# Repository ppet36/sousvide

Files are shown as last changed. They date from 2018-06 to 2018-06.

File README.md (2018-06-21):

# DIY Sous Vide cooker

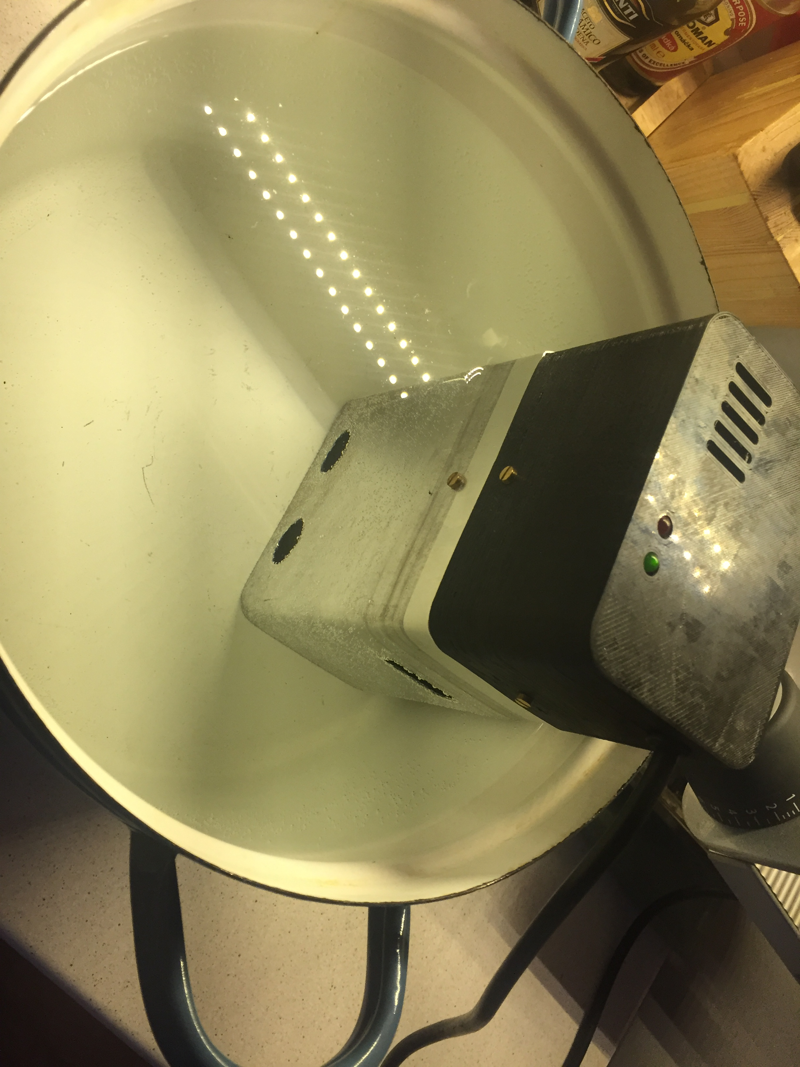
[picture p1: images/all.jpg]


This repository contains resources for my DIY WiFi Sous Vide cooker. Repo contains
responsive Angular/Bootstrap application for setting cooking parameters and manage
cooker, Eagle PCB design w/ schematic and 3D model of enclosure.

Cooker are based on ESP12E (or ESP07) module, submersible heater PROFESSOR PO500 and
EHEIM Compact 300 aquarium pump.
For measuring temperature watertight DS18B20 sensor is used. Analog
ESP PIN is used for detecting water level and protecting "dry" run of cooker.
Some parts are printed on 3D printer, bottom part of cooker is bended aluminium
sheet.

Memory of ESP12E is divided into two parts; 1M for firmware and 3M for SPIFFS.
Application (arduino/data/*) is uploaded to ESP's SPIFFS and is served via
internal HTTP server. Firmware creates AP SousVideCooker with listening HTTP server
at:

```
http://192.168.4.1/
```
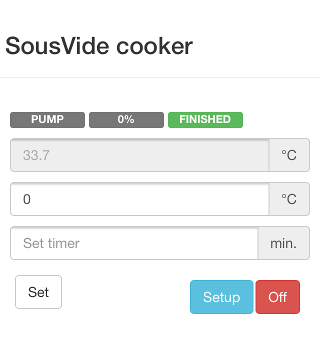
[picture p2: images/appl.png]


AP password is defaulted to 123456 and can be set in fw source file.

Via application can be also set PID parameters for heater. Firmware uses AutoPID
library from https://github.com/r-downing/AutoPID.
Also other Arduino libraries is used https://github.com/milesburton/Arduino-Temperature-Control-Library,
https://github.com/bblanchon/ArduinoJson ...

Heater as well as pump is driven via triacs. Duo MOC3041/BT136 is used for heater
and plain MOC3041 for pump (which is only 5W). For 500W heater is not needed
additional BT136 cooling but small TO220 heatsink is suitable.

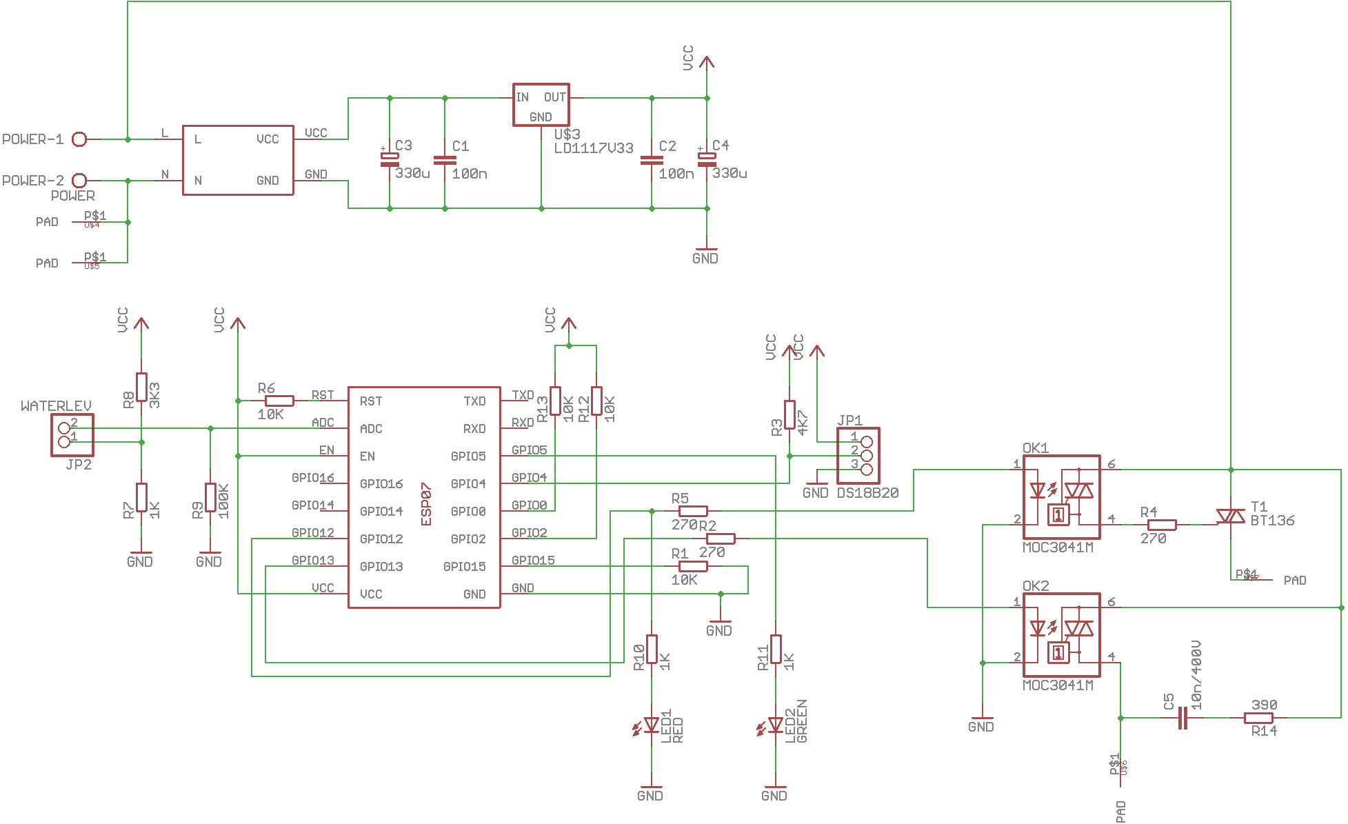
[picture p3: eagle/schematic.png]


Module is powered via 5V/1A PSU. Many of theses is on ebay; for example:
https://www.ebay.com/sch/i.html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
You can use also 3.3V PSU instead of 5V; so linear regulator is not needed.

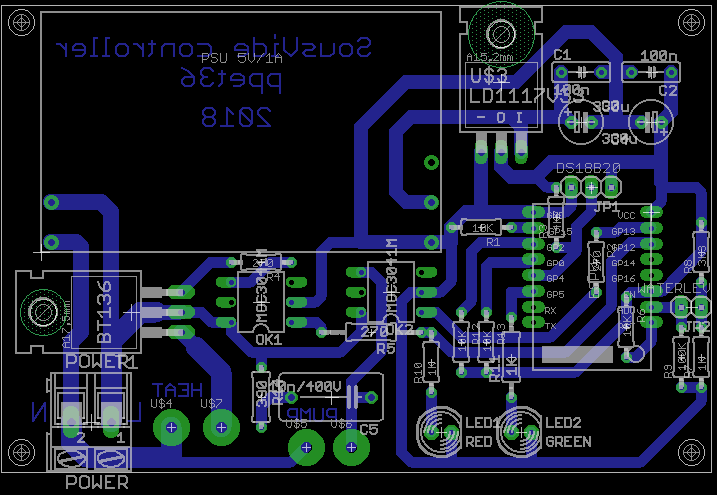
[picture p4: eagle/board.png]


PCB is designed to fit on top of mounting cube. All connections (except of power supply cord)
is connected from bottom side of PCB.

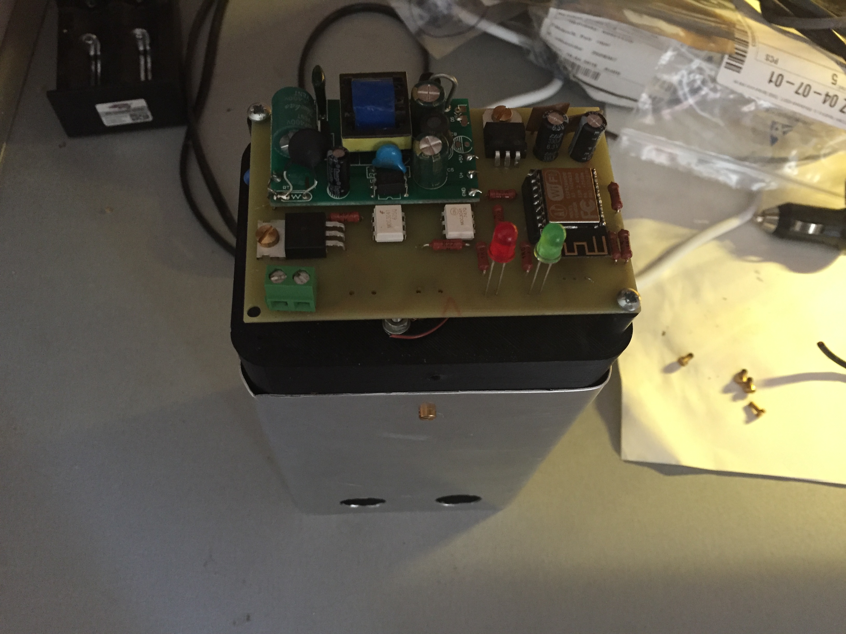
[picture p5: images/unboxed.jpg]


(PCB in image is working prototype and not looking exactly same as in eagle/* resources;
I modified schematic and PCB layout later taking experiences into account)

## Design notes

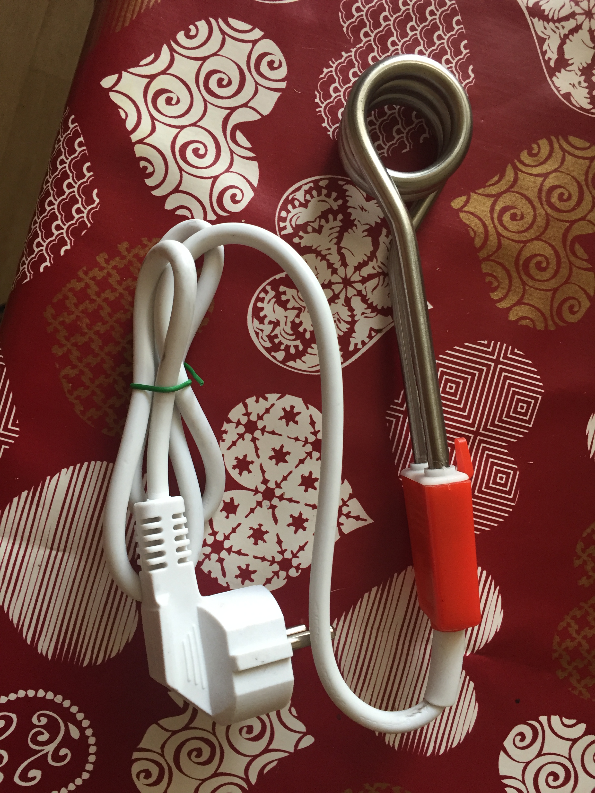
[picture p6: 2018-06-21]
images/heater.jpg

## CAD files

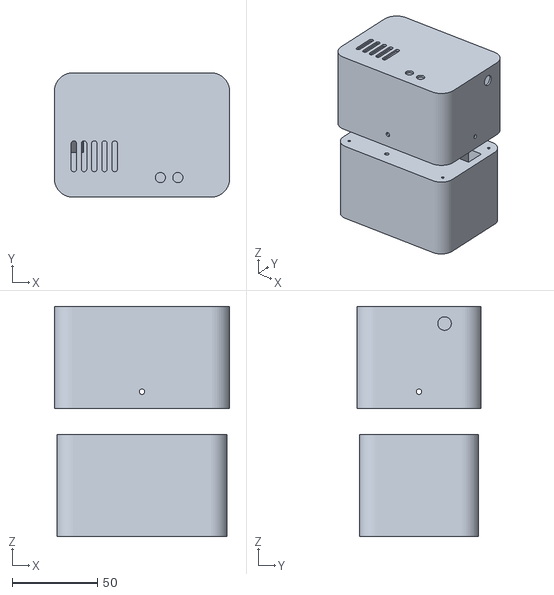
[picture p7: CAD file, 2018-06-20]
openscad/svbox.stl
103.0 x 73.0 x 135.0

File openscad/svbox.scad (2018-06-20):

$fn=30;

module roundedRect(size, radius) {
  x = size[0];
  y = size[1];
  z = size[2];

  translate([0,0,-z/2]) linear_extrude (height=z) hull($fn=50) {
    translate([(-x/2)+(radius/2), (-y/2)+(radius/2), 0])
    circle(r=radius);

    translate([(x/2)-(radius/2), (-y/2)+(radius/2), 0])
    circle(r=radius);

    translate([(-x/2)+(radius/2), (y/2)-(radius/2), 0])
    circle(r=radius);

    translate([(x/2)-(radius/2), (y/2)-(radius/2), 0])
    circle(r=radius);
  }
}

module eheimPump() {
  union() {
    cube ([42, 34, 28], center=true);
    translate([-28,0,-20]) rotate([0,90,0]) cylinder (d=12, h=15, center=true, $fn=50);
    translate([15,9.5,28]) cube ([12, 15, 30], center=true);
    translate([0,0,-25]) cube ([42, 34, 22], center=true);
    translate([28,0,-31]) cube ([15,34,10], center=true);
    translate([-20,0,-33]) rotate([90,0,0]) cylinder (d=50, h=34, center=true, $fn=100);
  }
}

module heater() {
  union() {
   hull() {
     translate([0,0,20]) cube ([10, 20, 1], center=true);
     translate([0,0,-20]) cube ([10, 24.5, 1], center=true);
   }
   translate([0,0,30]) cylinder (d=7, h=20, center=true, $fn=30);
   translate([0,0,-45.5]) cube ([14,29,50], center=true);
  }
}

module toCut() {
  translate([-30,0,0]) {
    translate([-5,0,13]) rotate([0,-15,0]) heater();
    translate([53,0,-5]) eheimPump();
    //translate([55,25,0]) cube([5,2,200], center=true);
    //translate([55,-25,0]) cube([5,2,200], center=true);
    translate([20,12,-25]) ds18b20();
    translate([20,-25,-25]) cylinder (d=3.2, h=200, center=true, $fn=30);
    translate([20,25,-25]) cylinder (d=3.2, h=200, center=true, $fn=30);
  }
}

module holderBox() {
  difference() {
    roundedRect ([90, 60, 60], 10); 
    toCut();
  
    translate([-43,-27,21]) cylinder (d=2, h=20, center=true);
    translate([-43,27,21]) cylinder (d=2, h=20, center=true);
    translate([43,-27,21]) cylinder (d=2, h=20, center=true);
    translate([43,27,21]) cylinder (d=2, h=20, center=true);
  }
}

module ds18b20() {
  union() {
    cylinder (d=6, h=35, center=true, $fn=50);
    translate([0,0,25]) cylinder (d=6.5, h=15, center=true, $fn=50);
    translate([0,0,57]) cylinder (d=6.5, h=50, center=true, $fn=50);
  }
}

module vetrani() {
  hull() {
    cylinder (d=3.2, h=100, center=true);
    translate([0,15,0]) cylinder (d=3.2, h=100, center=true);
  }
}

module okraj() {
  difference() {
    union() {
      translate([0,0,29.25]) roundedRect ([92, 62, 1.5], 10);
      difference() {
        roundedRect([92, 62, 60], 11);
        roundedRect([90.3, 60.3, 60.1], 10);
      }
    }
    
    translate([-45+55.8,-30+5,0]) cylinder (d=6, h=200, center=true);
    translate([-45+66.04,-30+5,0]) cylinder (d=6, h=200, center=true);
    translate([0,0,-20]) rotate([90,0,0]) cylinder (d=3.2, h=200, center=true);
    translate([0,0,-20]) rotate([90,0,90]) cylinder (d=3.2, h=200, center=true);
    translate([50,15,20]) rotate([90,0,90]) cylinder (d=8, h=50, center=true);
    
    translate([-40,-20,0]) vetrani();
    translate([-40+6,-20,0]) vetrani();
    translate([-40+12,-20,0]) vetrani();
    translate([-40+18,-20,0]) vetrani();
    translate([-40+24,-20,0]) vetrani();
  }
}

module vyrez() {
   rotate([0,-90,0]) 
   hull() {
     cube ([30,30,5], center=true);
     translate([20,0,0]) cylinder (d=30, h=5, center=true);
   }  
}

holderBox();
translate([0,0,75]) okraj();

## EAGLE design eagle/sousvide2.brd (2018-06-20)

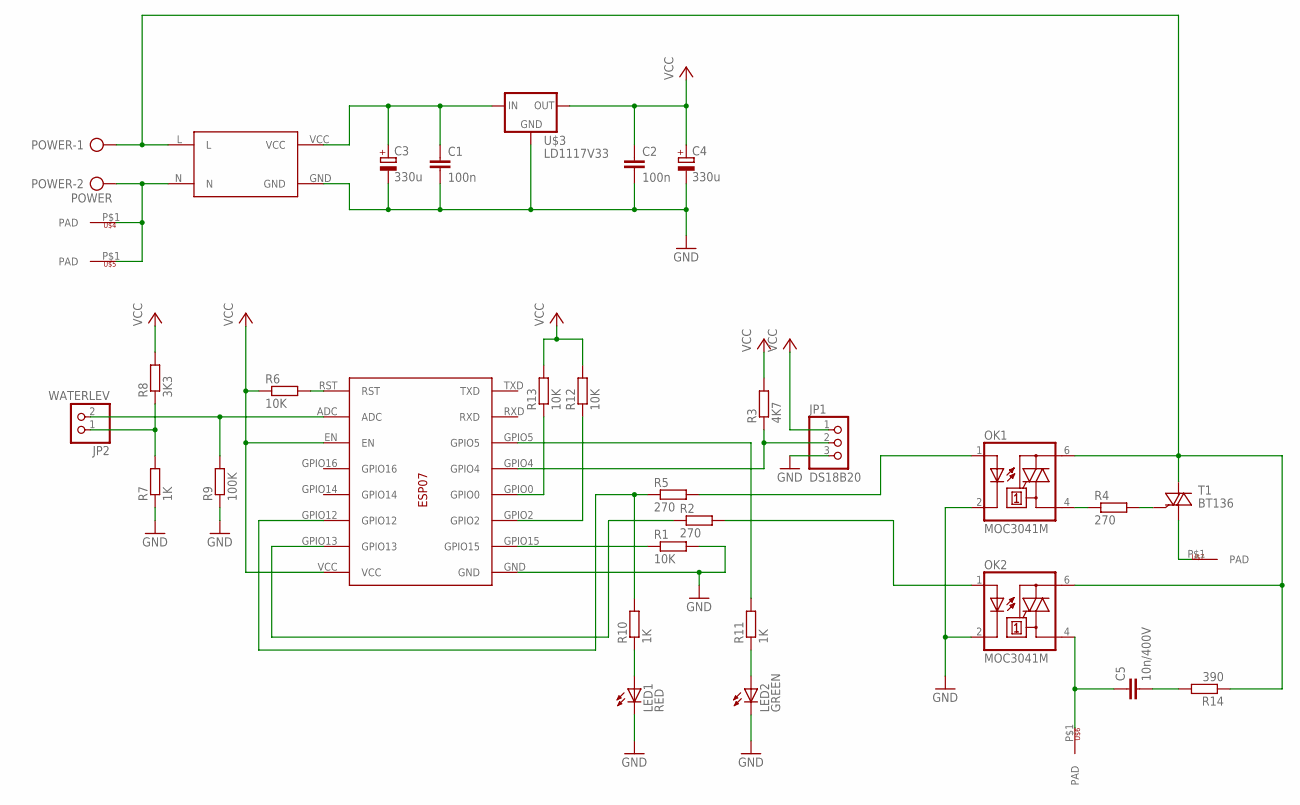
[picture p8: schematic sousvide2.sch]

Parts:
C1, C2: 100n; C050-025X075
C3, C4: 330u; E2,5-6
C5: 10n/400V; C102-064X133
JP1: DS18B20; 1X03
JP2: WATERLEV; 1X02
LED1: RED; LED5MM
LED2: GREEN; LED5MM
OK1, OK2: MOC3041M; DIL06
POWER: POWER; AK300/2
R1, R6, R12, R13: 10K; 0204/7
R2, R4: 270; 0204/7
R3: 4K7; 0204/7
R5: 270; 0207/12
R7, R10: 1K; 0204/7
R8: 3K3; 0204/7
R9: 100K; 0204/7
R11: 1K; 0207/10
R14: 390; 0207/7
T1: BT136; TO220AB
U$1: ESP12F; ESP07
U$2: PSU5V1A; PSU5V
U$3: LD1117V33
U$4, U$5, U$6, U$7: PAD

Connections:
GND: C1.2, C2.2, C3.-, C4.-, JP1.3, LED1.K (C), LED2.K (C), OK1.2 (C), OK2.2 (C), R1.2, R7.1, R9.1, U$1.GND, U$2.GND, U$3.GND
unnamed: R1.1, U$1.GPIO15
unnamed: R2.1, U$1.GPIO13
unnamed: OK1.4 (A1), R4.1
unnamed: R4.2, T1.3 (G)
unnamed: C1.1, C3.+, U$2.VCC, U$3.IN
unnamed: POWER.2, U$2.N, U$4.P$1, U$5.P$1
unnamed: OK1.6 (A2), OK2.6 (A2), POWER.1, R14.1, T1.2 (A2), U$2.L
unnamed: LED1.A, R10.1
unnamed: T1.1 (A1), U$7.P$1
unnamed: R13.1, U$1.GPIO0
unnamed: R5.1, R10.2, U$1.GPIO12
unnamed: OK1.1 (A), R5.2
unnamed: LED2.A, R11.1
unnamed: OK2.1 (A), R2.2
unnamed: R11.2, U$1.GPIO5
unnamed: C5.1, OK2.4 (A1), U$6.P$1
unnamed: JP1.2, R3.1, U$1.GPIO4
unnamed: R12.1, U$1.GPIO2
unnamed: R6.2, U$1.RST
unnamed: JP2.2, R9.2, U$1.ADC
unnamed: JP2.1, R7.2, R8.1
unnamed: C5.2, R14.2
VCC: C2.1, C4.+, JP1.1, R3.2, R6.1, R8.2, R12.2, R13.2, U$1.EN, U$1.VCC, U$3.OUT

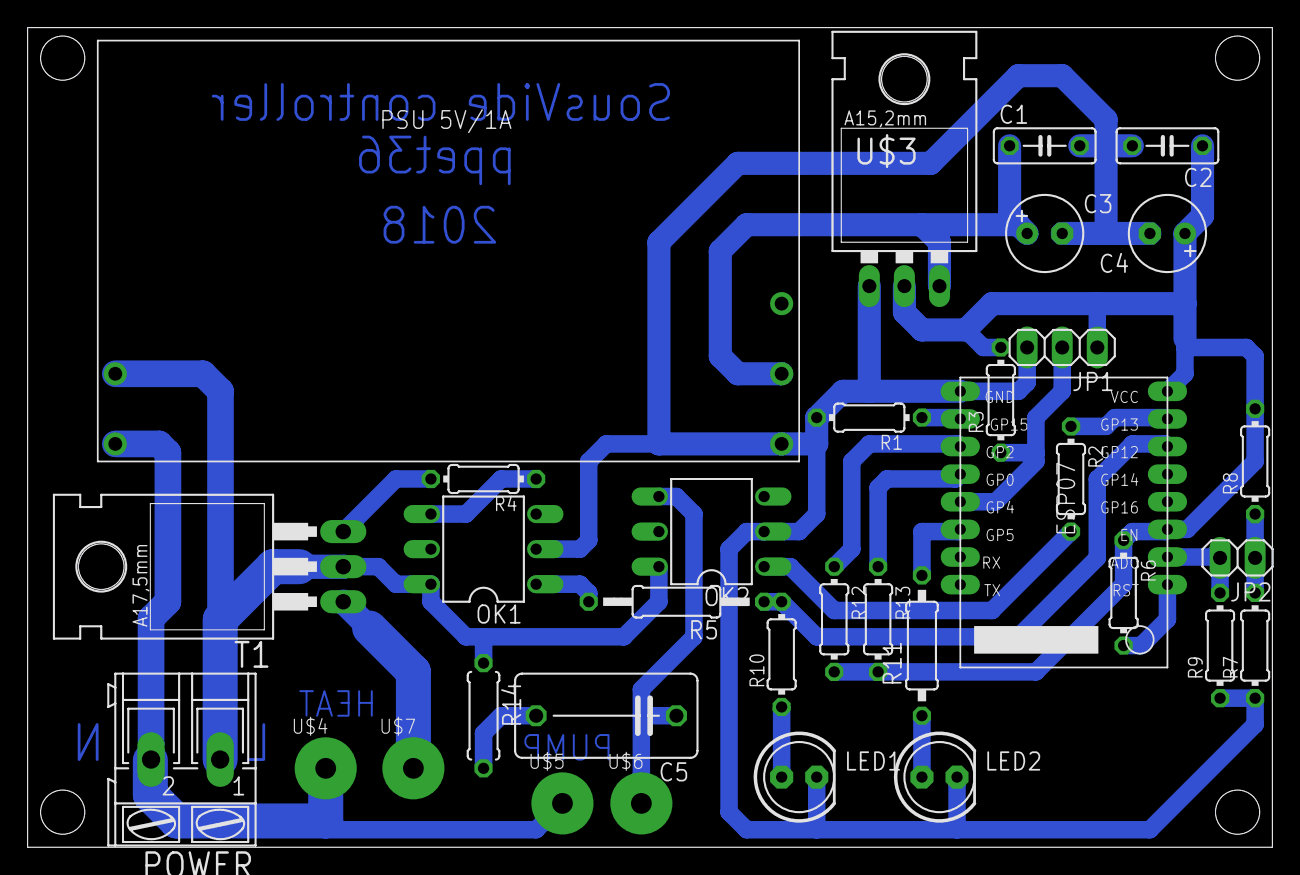
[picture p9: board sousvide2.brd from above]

Board: 2 copper layers, 90.2 x 59.4 mm, 34 parts (0 on the bottom side), 24 nets.

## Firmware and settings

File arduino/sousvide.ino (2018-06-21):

/**
 * SousVide controller for ESP12F or ESP07.
 *
 * Pins asignment:
 *
 * ADC     - water level sensor.
 * GPIO12  - triac switch for heater.
 * GPIO13  - triac switch for pump.
 * GPIO4   - OneWire DS18B20
 * GPIO5   - green status led.
 *
 * Code uses ArduinoJson, SPIFFS and OTA library.
 *
 * @author ppet36
*/
#include <AutoPID.h>
#include <DallasTemperature.h>
#include <OneWire.h>
#include <EEPROM.h>
#include <ESP8266WiFi.h>
#include <ESP8266HTTPClient.h>
#include <WiFiClient.h>
#include <ESP8266WebServer.h>
#include <FS.h>
#include <ArduinoJson.h>
#include <ArduinoOTA.h>

// WIFI
#define WIFI_AP_SSID "SousVideCooker"
#define WIFI_AP_PWD "123456"
#define WEB_SERVER_PORT 80

#define PIN_WATER_LEVEL A0
#define PIN_HEATER      12
#define PIN_PUMP        13
#define PIN_ONEWIRE     4
#define PIN_STATUS      5

// PWM heater window size
#define PWM_HEATER_WINDOW_SIZE    5000

// PID settings
#define DEFAULT_KP 0.12
#define DEFAULT_KI 0.0003
#define DEFAULT_KD 0
#define DEFAULT_PID_BANG 1.0

// DS18B20 temp is readed once 800ms
#define TEMP_READ_DELAY 800

// ADC value (greater values means enough water)
#define WATER_LEVEL_LIMIT  350

// States
#define ST_OFF      0x00
#define ST_NO_WATER 0x01
#define ST_RUNNING  0x02
#define ST_FINISHED 0x03

// Current eeprom magic for detecting unconfigured module
#define MAGIC 0xAA

// EEPROM structure for configuration
struct SvConfiguration {
  int magic;
  double kp;
  double ki;
  double kd;
  double bang;
};

// DS18B20
OneWire oneWire (PIN_ONEWIRE);
DallasTemperature temperatureSensors (&oneWire);

// PID values
double curTemperature, reqTemperature;
bool heaterVal;

// PID
AutoPIDRelay myPID (&curTemperature, &reqTemperature, &heaterVal, PWM_HEATER_WINDOW_SIZE, DEFAULT_KP, DEFAULT_KI, DEFAULT_KD);

// Configuration server
ESP8266WebServer server (WEB_SERVER_PORT);

// Water level indication
int waterLevelAdc;
bool waterLevel;

// Timer; requested time (mins)
unsigned long timerStopTime = 0UL;
int timerMins = 0;
bool timerTargetTempReached = true;

// Configuration
SvConfiguration config;

// Current state
int state;

// Last heater on time
unsigned long lastHeaterOnTime = 0UL;
unsigned long lastHeaterOffTime = 0UL;


/**
 * setup() functions.
*/
void setup() {
  Serial.begin (115200);

  waterLevel = false;

  pinMode (PIN_HEATER, OUTPUT);
  pinMode (PIN_PUMP, OUTPUT);
  pinMode (PIN_STATUS, OUTPUT);

  digitalWrite (PIN_HEATER, LOW);
  digitalWrite (PIN_PUMP, LOW);
  digitalWrite (PIN_STATUS, LOW);

  delay (5000);

  // network FW upgrade
  ArduinoOTA.setHostname ("SousVide");
  ArduinoOTA.begin();

  // filesystem
  SPIFFS.begin();

  // init DS18B20
  temperatureSensors.begin();
  temperatureSensors.requestTemperatures();
  while (!updateTemperature()) {}

  reqTemperature = 0.0;

  // read configuration
  EEPROM.begin (sizeof (SvConfiguration));
  EEPROM.get (0, config);

  if (config.magic != MAGIC) {
    // if magic does not match, update with default values
    memset (&config, 0, sizeof (SvConfiguration));
    config.magic = MAGIC;
    config.kp = DEFAULT_KP;
    config.ki = DEFAULT_KI;
    config.kd = DEFAULT_KD;
    config.bang = DEFAULT_PID_BANG;
    EEPROM.put (0, config);
  }

  EEPROM.end();

  // init PID
  updatePidByConfig();

  WiFi.disconnect(true);

  WiFi.mode(WIFI_AP);

  // start WiFi
  WiFi.hostname (F("SousVide"));

  if (WiFi.softAP (WIFI_AP_SSID, WIFI_AP_PWD)) {
    Serial.print (F("Created AP: ")); Serial.println (WIFI_AP_SSID);
  }
  
  delay (500);

  server.on ("/cmd", HTTP_POST, wsHandleCmd);
  server.on ("/setup", wsHandleSetup);
  server.onNotFound([]() {
    if (!handleFileRead(server.uri())) {
      server.send(404, "text/plain", "404: Not Found");
    }
  });

  server.begin();
  Serial.print (F("Created HTTP server at ")); Serial.print (WiFi.softAPIP()); Serial.print (F(":")); Serial.println (WEB_SERVER_PORT);

  state = ST_OFF;

  delay(500);
}

/**
 * Update PID by configuration.
*/
void updatePidByConfig() {
  myPID.setBangBang (config.bang);
  myPID.setGains (config.kp, config.ki, config.kd);
}

/**
 * Simple routine to get content type of file.
 *
 * @param filename filename.
 * @return String content type.
*/
String getContentType (String filename) {
  if (filename.endsWith(".html")) {
    return "text/html";
  } else if (filename.endsWith(".css")) {
    return "text/css";
  } else if (filename.endsWith(".js")) {
    return "application/javascript";
  } else if (filename.endsWith(".ico")) {
    return "image/x-icon";
  } else if (filename.endsWith (".png")) {
    return "image/png";
  } else {
    return "text/plain";
  }
}

/**
 * Handles SPIFFS file read.
 *
 * @param path path.
 * @return bool success?
*/
bool handleFileRead (String path) {
  Serial.print(F("handleFileRead (")); Serial.print (path); Serial.print (F(")"));

  if (path.endsWith("/")) {
    path += "index.html";
  }

  String pathWithGz = path + ".gz";

  String foundPath;

  if (SPIFFS.exists (path)) {
    foundPath = path;
  } else if (SPIFFS.exists (pathWithGz)) {
    foundPath = pathWithGz;
  } else {
    Serial.println (F(" File Not Found"));
    return false;
  }

  String contentType = getContentType (path);

  Serial.print (F(" -> ")); Serial.print (foundPath);

  File file = SPIFFS.open (foundPath, "r");
  if (foundPath.endsWith (".gz")) {
    server.sendHeader (F("Content-Encoding"), F("gzip"));
  }
  server.sendHeader (F("Cache-Control"), F("public,max-age=86400"));

  char buf[1024];
  int siz = file.size();

  int toTransfer = siz;

  server.setContentLength (siz);
  server.send (200, contentType, "");
  delay (250);

  while (siz > 0) {
    size_t len = std::min ((int)(sizeof(buf) - 1), siz);
    file.read ((uint8_t *)buf, len);
    server.client().write ((const char*)buf, len);
    Serial.print (F("."));
    delay (100);
    yield();
    siz -= len;
  }
  file.close();

  server.client().stop();

  Serial.print(F(" sent ")); Serial.print (toTransfer); Serial.println (F(" bytes; SUCCESS"));
  return true;
}

/**
 * Update DS18B20 temperature.
 *
 * @return bool success?
*/
bool updateTemperature() {
  static unsigned long lastTempUpdate = millis();

  if ((millis() - lastTempUpdate) > TEMP_READ_DELAY) {
    curTemperature = temperatureSensors.getTempCByIndex (0);

    if ((curTemperature >= reqTemperature) && !timerTargetTempReached) {
      timerStopTime = millis() + (timerMins * 60000UL);
      timerTargetTempReached = true;
    }

    lastTempUpdate = millis();
    temperatureSensors.requestTemperatures();
    return true;
  } else {
    return false;
  }
}

/**
 * Maintains heater.
*/
void maintainHeater() {
  myPID.run();

  if (waterLevel) {
    digitalWrite (PIN_HEATER, heaterVal ? HIGH : LOW);

    static bool lastHeaterState = heaterVal;
    static unsigned long lastHeaterStateChange = millis();

    if (heaterVal != lastHeaterState) {
      if (heaterVal) {
        lastHeaterOffTime = millis() - lastHeaterStateChange;
      } else {
        lastHeaterOnTime = millis() - lastHeaterStateChange;
      }

      lastHeaterState = heaterVal;
      lastHeaterStateChange = millis();
    }
  } else {
    digitalWrite (PIN_HEATER, LOW);
  }
}

/**
 * Updates status led.
*/
void checkWaterLevel() {
  waterLevelAdc = analogRead (PIN_WATER_LEVEL);

  waterLevel = (waterLevelAdc > WATER_LEVEL_LIMIT);

  if (!waterLevel) {
    state = ST_NO_WATER;
    digitalWrite (PIN_HEATER, LOW);
    digitalWrite (PIN_PUMP, LOW);
  } else {
    if (reqTemperature > 0.0) {
      digitalWrite (PIN_PUMP, HIGH);
    } else {
      digitalWrite (PIN_PUMP, LOW);
    }

    if (state == ST_NO_WATER) {
      state = ST_OFF;
    }
  }
}

/**
 * Updates status led.
*/
void updateStatusLed() {
  static unsigned long ledLastBlink = millis();

  bool curLedState = (digitalRead(PIN_STATUS) == HIGH);

  int onTime, offTime;

  if (state == ST_OFF) {
    onTime = 250;
    offTime = 3000;
  } else if (state == ST_NO_WATER) {
    onTime = 0;
    offTime = 1;
  } else if (state == ST_RUNNING) {
    onTime = 300;
    offTime = 300;
  } else if (state == ST_FINISHED) {
    onTime = 1;
    offTime = 0;
  }

  if (onTime == 0) {
    digitalWrite (PIN_STATUS, LOW);
  } else if (offTime == 0) {
    digitalWrite (PIN_STATUS, HIGH);
  } else {
    int time = (curLedState ? onTime : offTime);

    if ((millis() - ledLastBlink) >= time) {
      if (curLedState) {
        digitalWrite (PIN_STATUS, LOW);
      } else {
        digitalWrite (PIN_STATUS, HIGH);
      }
      ledLastBlink = millis();
    }
  }
}

/**
 * Command handler.
*/
void wsHandleCmd() {
  StaticJsonDocument<200> newDoc;
  DeserializationError err = deserializeJson (newDoc, server.arg ("plain"));
  if (err) {
    server.send (400, "text/plain", "Bad request!");
    return;
  }
  JsonObject& newjson = newDoc.as<JsonObject>();

  Serial.print (F("CMD=")); Serial.println (server.arg ("plain"));

  JsonVariant v = newjson["reqTemperature"];
  if (v.success()) {
    reqTemperature = v | 0.0;
    timerStopTime = 0UL;

    if (reqTemperature > 0.0) {
      state = ST_RUNNING;
    } else if ((state == ST_RUNNING) || (state == ST_FINISHED)) {
      state = ST_OFF;
    }

    Serial.print (F("Setting requested temperature to ")); Serial.println (reqTemperature);
  }

  v = newjson["timerMins"];
  if (v.success()) {
    timerMins = v | 0;

    if (timerMins == 0) {
      timerStopTime = 0UL;
      timerTargetTempReached = true;
      Serial.println (F("Reset timer..."));
    } else {
      timerStopTime = millis() + (timerMins * 60000UL);
      timerTargetTempReached = false;
      Serial.print (F("Setting timer to ")); Serial.print (v | 0); Serial.println (F(" mins."));
    }
  }

  int heaterPercent;
  if (state == ST_RUNNING) {
    if ((lastHeaterOnTime == 0) || (lastHeaterOffTime == 0)) {
      heaterPercent = digitalRead(PIN_HEATER) ? 100 : 0;
    } else {
      heaterPercent = lastHeaterOffTime * 100L / (lastHeaterOnTime + lastHeaterOffTime);
    }
  } else {
    heaterPercent = 0;
  }

  String resp = F("{ ");
  resp += F("\"curTemperature\" : ");
  resp += String(curTemperature, 1);
  resp += F(", \"reqTemperature\" : ");
  resp += String(reqTemperature, 1);
  resp += F(", \"waterLevel\" : ");
  resp += String(waterLevel);
  resp += F(", \"heaterState\" : ");
  resp += String(digitalRead (PIN_HEATER));
  resp += F(", \"heaterPercent\" : ");
  resp += String(heaterPercent);
  resp += F(", \"pumpState\" : ");
  resp += String(digitalRead (PIN_PUMP));

  if (timerMins > 0) {
    resp += F(", \"remainingMins\" : ");
    if (timerTargetTempReached) {
      resp += String((timerStopTime - millis()) / 60000UL);
    } else {
      resp += String(timerMins);
    }
  }

  resp += F(", \"timerStateString\" : \"");
  if (timerMins > 0) {
    if (timerTargetTempReached) {
      unsigned long millisTimerTime = timerStopTime - millis();
      if (millisTimerTime < 60000UL) {
        resp += String(millisTimerTime / 1000UL);
        resp += F(" secs remaining");
      } else {
        resp += String(millisTimerTime / 60000UL);
        resp += F(" mins remaining");
      }
    } else {
      resp += F("Reaching target temperature...");
    }
  } else {
    resp += F("Set timer");
  }
  resp += F("\"");

  resp += F(", \"state\" : \"");
  switch (state) {
    case ST_OFF :
      resp += "OFF";
    break;
    case ST_NO_WATER :
      resp += "!NO_WATER!";
    break;
    case ST_RUNNING : 
      resp += "RUNNING";
    break;
    case ST_FINISHED :
      resp += "FINISHED";
    break;
    default : break;
  }

  resp += F("\" }");

  Serial.print (F("RESPONSE= "));
  Serial.println (resp);

  server.send (200, "text/json", resp);
}

/**
 * Convert variant to double.
 *
 * @param v variant.
 * @return double double.
*/
double variantToDouble (JsonVariant& v) {
  String s = v | "";
  return s.toFloat();
}

/**
 * Handles configuration.
*/
void wsHandleSetup() {
  if (server.method() == HTTP_POST) {
    StaticJsonDocument<200> newDoc;
    DeserializationError err = deserializeJson (newDoc, server.arg ("plain"));
    if (err) {
      server.send (400, "text/plain", "Bad request!");
      return;
    }
    JsonObject& newjson = newDoc.as<JsonObject>();

    Serial.print (F("CMD=")); Serial.println (server.arg ("plain"));

    JsonVariant v = newjson["kp"];
    if (v.success()) {
      config.kp = variantToDouble (v);
    }
    v = newjson["ki"];
    if (v.success()) {
      config.ki = variantToDouble (v);
    }
    v = newjson["kd"];
    if (v.success()) {
      config.kd = variantToDouble (v);
    }
    v = newjson["bang"];
    if (v.success()) {
      config.bang = variantToDouble (v);
    }

    // update PWM parameters
    updatePidByConfig();

    // save to EEPROM
    EEPROM.begin (sizeof (SvConfiguration));
    EEPROM.put (0, config);
    EEPROM.end();
  } else {
    server.sendHeader (F("Cache-Control"), F("private,no-cache,must-revalidate"));
  }

  // response GET/POST is always JSON configuration structure
  String resp = F("{ ");
  resp += F("\"kp\" : ");
  resp += String(config.kp, 3);
  resp += F(", \"ki\" : ");
  resp += String(config.ki, 3);
  resp += F(", \"kd\" : ");
  resp += String(config.kd, 3);
  resp += F(", \"bang\" : ");
  resp += String(config.bang, 1);
  resp += F(" }");

  server.send (200, "text/json", resp);
}

/**
 * Updates timer function.
*/
void updateTimer() {
  if (timerMins > 0) {
    if (timerTargetTempReached && (millis() > timerStopTime)) {
      reqTemperature = 0.0;
      timerStopTime = 0UL;
      timerMins = 0;
      state = ST_FINISHED;
      Serial.println (F("Timer end triggered..."));
    }
  }
}

/**
 * Loop function.
*/
void loop() {
  ArduinoOTA.handle();

  updateTimer();

  updateTemperature();

  checkWaterLevel();

  updateStatusLed();

  maintainHeater();

  server.handleClient();

  static unsigned long lastStateLog = millis();
  if (millis() - lastStateLog > 5000UL) {
    Serial.print (F("STATE: "));
    Serial.print (curTemperature);
    Serial.print (F(" -> "));
    Serial.print (reqTemperature);
    Serial.print (F(", HEAT: "));
    Serial.print (digitalRead (PIN_HEATER));
    Serial.print (F(", WATER: "));
    Serial.print (waterLevel);
    Serial.print (F(" ("));
    Serial.print (waterLevelAdc);
    Serial.print (F("), PUMP: "));
    Serial.print (digitalRead (PIN_PUMP));
    Serial.print (F(", WIFISTAT: "));
    Serial.print (WiFi.softAPgetStationNum());
    Serial.println();

    lastStateLog = millis();
  }

  delay(250);
}
